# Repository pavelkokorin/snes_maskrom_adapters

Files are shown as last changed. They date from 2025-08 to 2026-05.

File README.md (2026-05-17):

# SNES/SFC Maskrom Adapters

## PSOP to DIP adapters
Adapters to replace SNES DIP32/DIP36 maskrom with PSOP44 Flash.

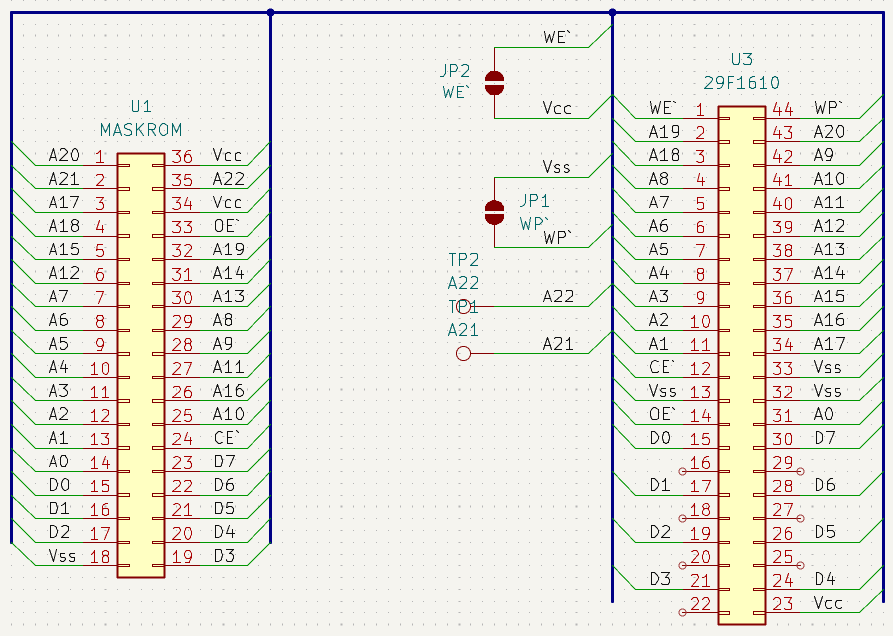
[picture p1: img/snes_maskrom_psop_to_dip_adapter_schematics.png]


### snes_maskrom_psop_to_dip_adapter
Backside PSOP44 to DIP36 adapter. Designed and tested for MX29F1610. Non destructive option, CE\`/OE\` pins of original maskrom should be cut.

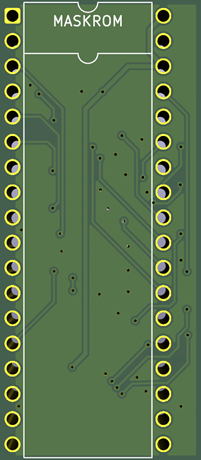
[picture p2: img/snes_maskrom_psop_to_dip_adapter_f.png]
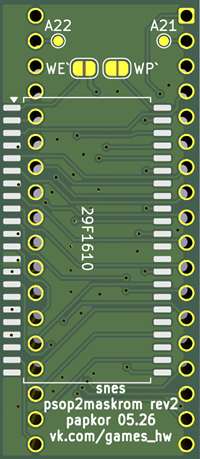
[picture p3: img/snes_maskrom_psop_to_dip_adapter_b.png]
 

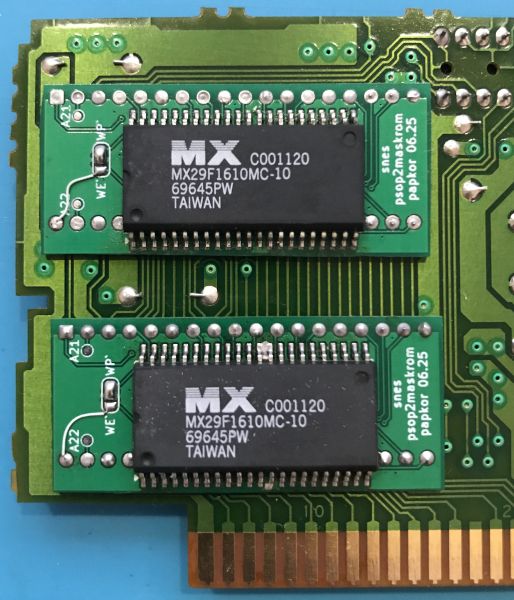
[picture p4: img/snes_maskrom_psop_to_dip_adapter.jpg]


### snes_maskrom_psop_to_dip_adapter_front
Fronside PSOP44 to DIP36 adapter. Designed and tested for MX29F1610. Replaces original maskrom.

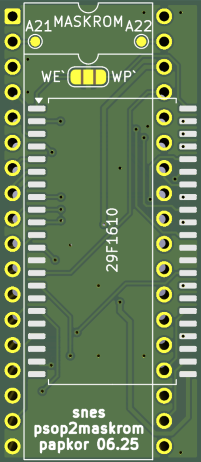
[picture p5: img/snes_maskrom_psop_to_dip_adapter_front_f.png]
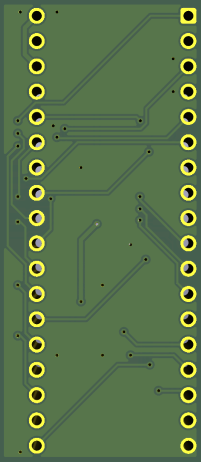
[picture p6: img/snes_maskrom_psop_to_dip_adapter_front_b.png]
 

## TSOP to DIP adapters
Adapters to replace SNES DIP32/DIP36 maskrom with TSOP40/TSOP48 Flash.

## snes_maskrom_tsop_to_dip_adapter
Backside TSOP40/TSOP48 to DIP36 adapter. Designed and tested for 29F032/29F033. Replaces original maskrom. Non destructive option, CE\`/OE\` pins of original maskrom should be cut.

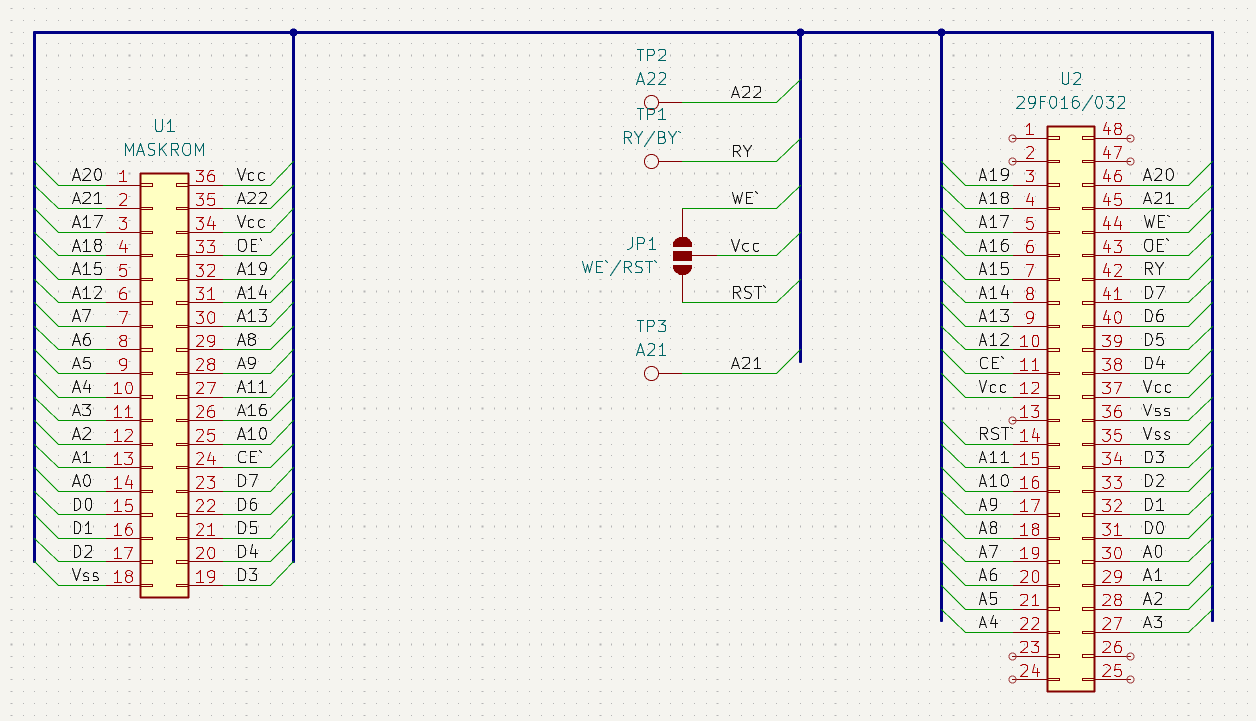
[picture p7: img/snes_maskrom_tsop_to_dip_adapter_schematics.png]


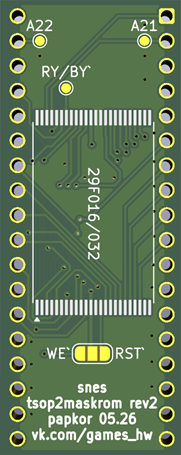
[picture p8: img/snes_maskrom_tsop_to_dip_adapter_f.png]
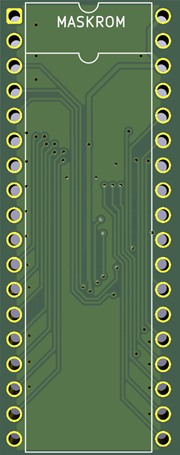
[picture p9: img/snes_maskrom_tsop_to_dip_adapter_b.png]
 

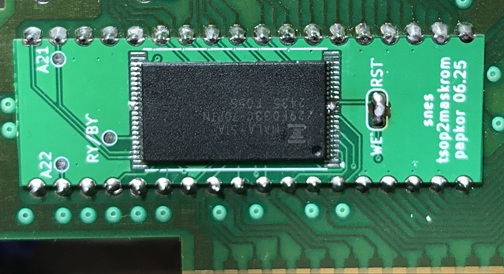
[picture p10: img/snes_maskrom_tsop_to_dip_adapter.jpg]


## snes_maskrom_tsop_to_fx_adapter
Adapters to replace SNES PSOP36/PSOP42 maskrom with TSOP40/TSOP48 Flash.

Maskroms: MX23C1601-12, M531610D-20, UPD23C4013 and other similar maskrom ICs.

Inspired by https://github.com/retrostage/SNES-SuperFX-adapter project.
Redesigned in KiCad to use less expensive production process, added some test points (WE#, RST#) for inschematic programming ability.

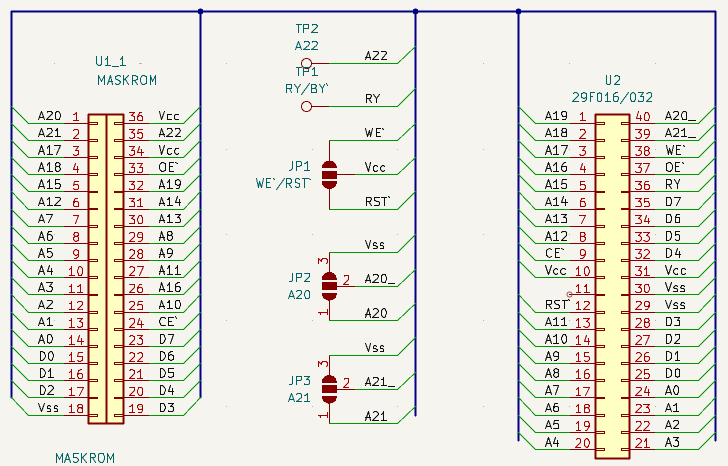
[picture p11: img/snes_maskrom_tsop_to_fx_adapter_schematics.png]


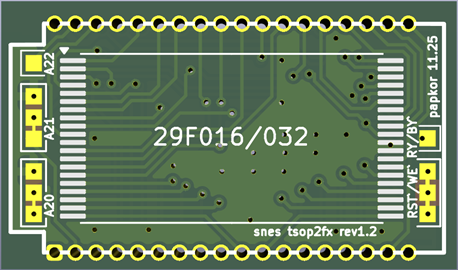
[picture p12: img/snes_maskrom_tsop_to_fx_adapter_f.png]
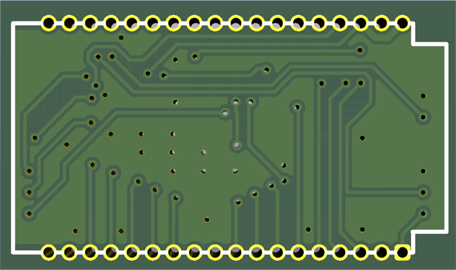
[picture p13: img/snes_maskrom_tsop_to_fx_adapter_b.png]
 

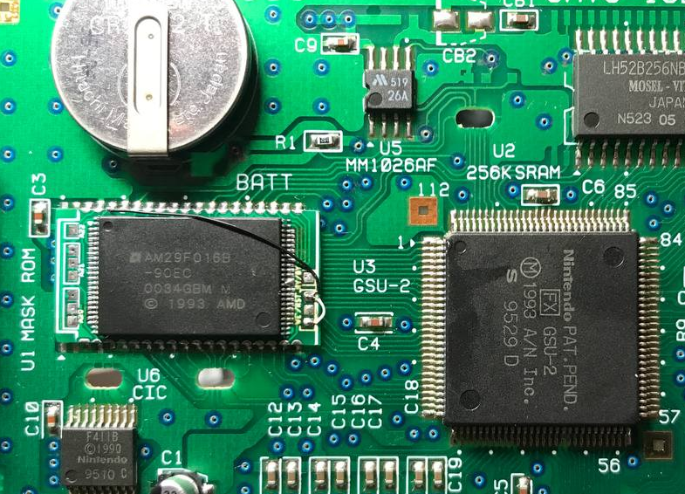
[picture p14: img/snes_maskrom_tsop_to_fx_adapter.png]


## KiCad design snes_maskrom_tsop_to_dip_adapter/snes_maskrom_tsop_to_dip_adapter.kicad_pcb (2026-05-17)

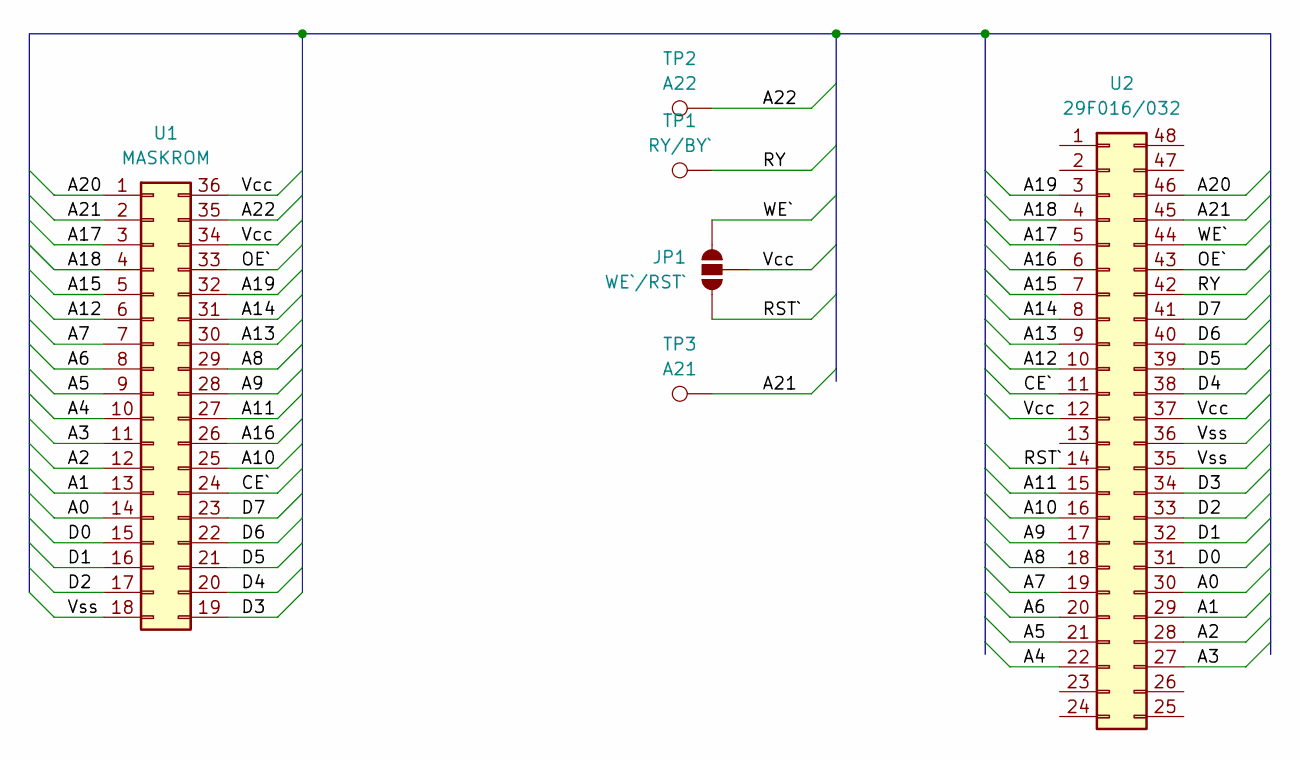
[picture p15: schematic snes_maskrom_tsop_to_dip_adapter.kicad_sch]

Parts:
JP1: WE`/RST`; SolderJumper-3_P1.3mm_Open_RoundedPad1.0x1.5mm_NumberLabels
TP1: RY/BY`; TestPoint_Pad_D1.0mm
TP2: A22; TestPoint_Pad_D1.0mm
TP3: A21; TestPoint_Pad_D1.0mm
U1: MASKROM; DIP-36_W15.24mm
U2: 29F016/032; TSOP-I-48_18.4x12mm_P0.5mm

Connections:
/A0: U1.14, U2.30
/A1: U1.13, U2.29
/A2: U1.12, U2.28
/A3: U1.11, U2.27
/A4: U1.10, U2.22
/A5: U1.9, U2.21
/A6: U1.8, U2.20
/A7: U1.7, U2.19
/A8: U1.29, U2.18
/A9: U1.28, U2.17
/A10: U1.25, U2.16
/A11: U1.27, U2.15
/A12: U1.6, U2.10
/A13: U1.30, U2.9
/A14: U1.31, U2.8
/A15: U1.5, U2.7
/A16: U1.26, U2.6
/A17: U1.3, U2.5
/A18: U1.4, U2.4
/A19: U1.32, U2.3
/A20: U1.1, U2.46
/A21: TP3.1, U1.2, U2.45
/A22: TP2.1, U1.35
/CE`: U1.24, U2.11
/D0: U1.15, U2.31
/D1: U1.16, U2.32
/D2: U1.17, U2.33
/D3: U1.19, U2.34
/D4: U1.20, U2.38
/D5: U1.21, U2.39
/D6: U1.22, U2.40
/D7: U1.23, U2.41
/OE`: U1.33, U2.43
/RST`: JP1.1 (A), U2.14
/RY: TP1.1, U2.42
/Vcc: JP1.2 (C), U1.34, U1.36, U2.12, U2.37
/Vss: U1.18, U2.35, U2.36
/WE`: JP1.3 (B), U2.44

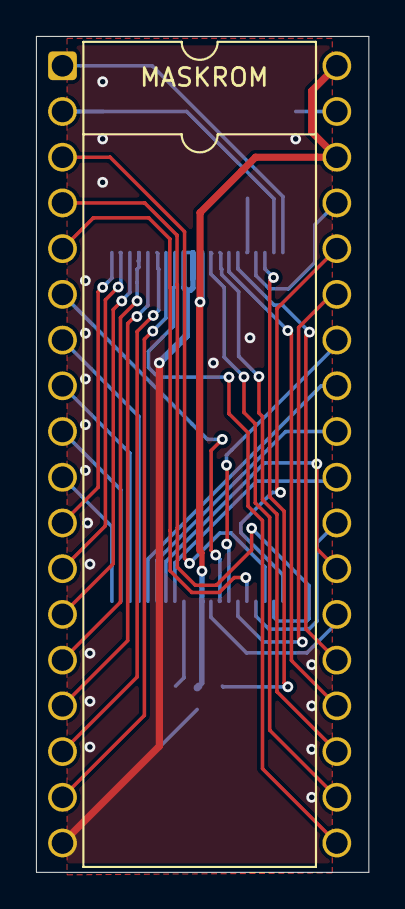
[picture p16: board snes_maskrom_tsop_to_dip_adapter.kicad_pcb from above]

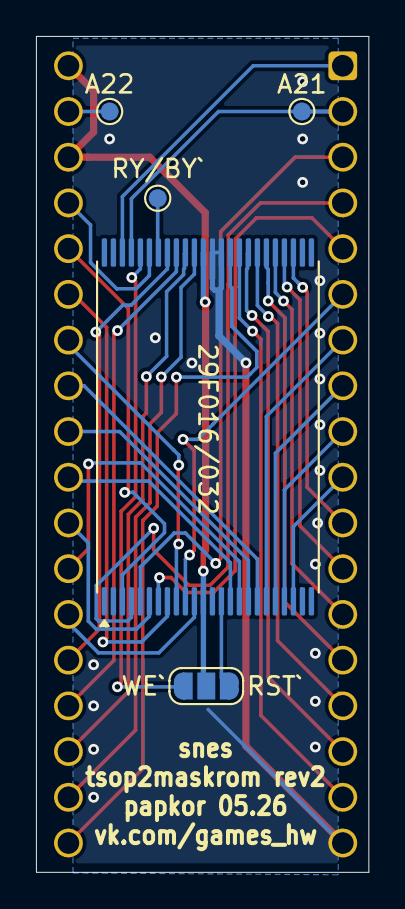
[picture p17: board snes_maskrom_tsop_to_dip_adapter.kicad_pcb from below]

Board: 2 copper layers, 18.5 x 46.4 mm, 6 parts (5 on the bottom side), 38 nets.

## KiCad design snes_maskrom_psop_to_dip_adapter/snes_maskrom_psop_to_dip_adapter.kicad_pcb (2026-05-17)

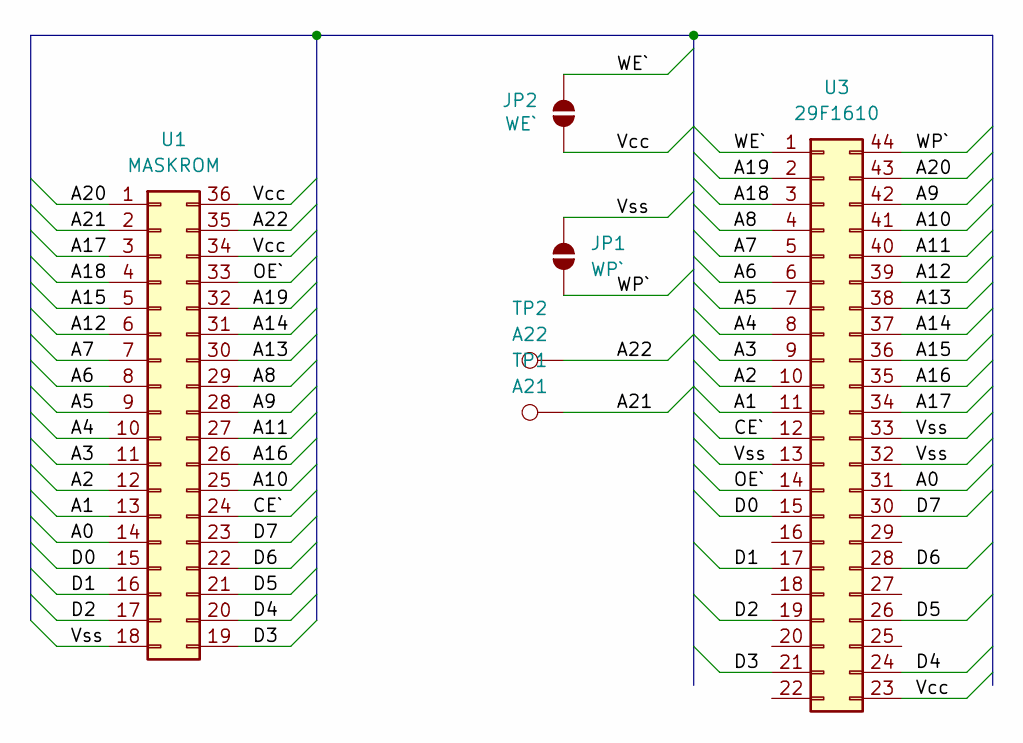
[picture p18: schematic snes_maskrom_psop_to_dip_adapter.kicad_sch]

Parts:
JP1: WP`; SolderJumper-2_P1.3mm_Open_RoundedPad1.0x1.5mm
JP2: WE`; SolderJumper-2_P1.3mm_Open_RoundedPad1.0x1.5mm
TP1: A21; TestPoint_Pad_D1.0mm
TP2: A22; TestPoint_Pad_D1.0mm
U1: MASKROM; DIP-36_W15.24mm
U3: 29F1610; SOP-44_12.6x28.5mm_P1.27mm

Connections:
/A0: U1.14, U3.31
/A1: U1.13, U3.11
/A2: U1.12, U3.10
/A3: U1.11, U3.9
/A4: U1.10, U3.8
/A5: U1.9, U3.7
/A6: U1.8, U3.6
/A7: U1.7, U3.5
/A8: U1.29, U3.4
/A9: U1.28, U3.42
/A10: U1.25, U3.41
/A11: U1.27, U3.40
/A12: U1.6, U3.39
/A13: U1.30, U3.38
/A14: U1.31, U3.37
/A15: U1.5, U3.36
/A16: U1.26, U3.35
/A17: U1.3, U3.34
/A18: U1.4, U3.3
/A19: U1.32, U3.2
/A20: U1.1, U3.43
/A21: TP1.1, U1.2
/A22: TP2.1, U1.35
/CE`: U1.24, U3.12
/D0: U1.15, U3.15
/D1: U1.16, U3.17
/D2: U1.17, U3.19
/D3: U1.19, U3.21
/D4: U1.20, U3.24
/D5: U1.21, U3.26
/D6: U1.22, U3.28
/D7: U1.23, U3.30
/OE`: U1.33, U3.14
/Vcc: JP2.1 (A), U1.34, U1.36, U3.23
/Vss: JP1.2 (B), U1.18, U3.13, U3.32, U3.33
/WE`: JP2.2 (B), U3.1
/WP`: JP1.1 (A), U3.44

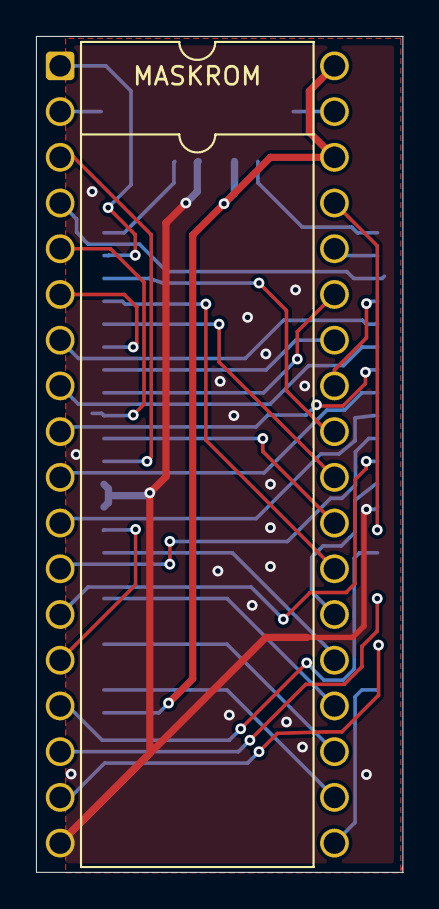
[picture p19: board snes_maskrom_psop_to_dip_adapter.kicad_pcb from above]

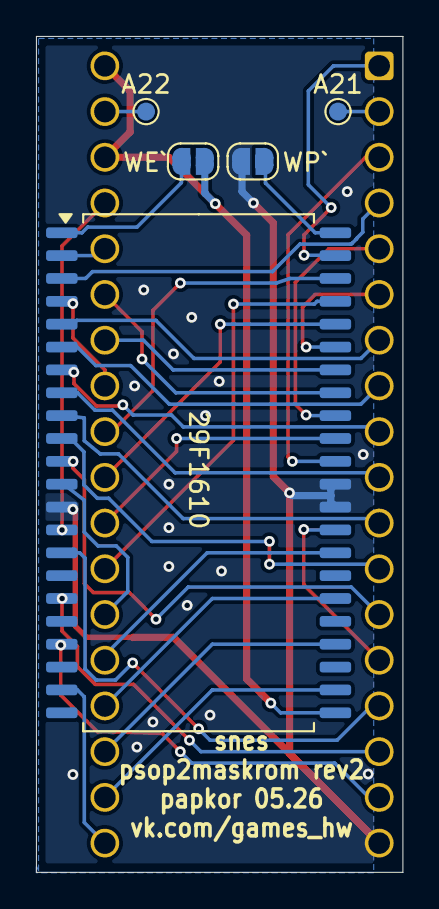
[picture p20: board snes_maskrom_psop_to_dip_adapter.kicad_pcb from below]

Board: 2 copper layers, 20.4 x 46.4 mm, 6 parts (5 on the bottom side), 37 nets.

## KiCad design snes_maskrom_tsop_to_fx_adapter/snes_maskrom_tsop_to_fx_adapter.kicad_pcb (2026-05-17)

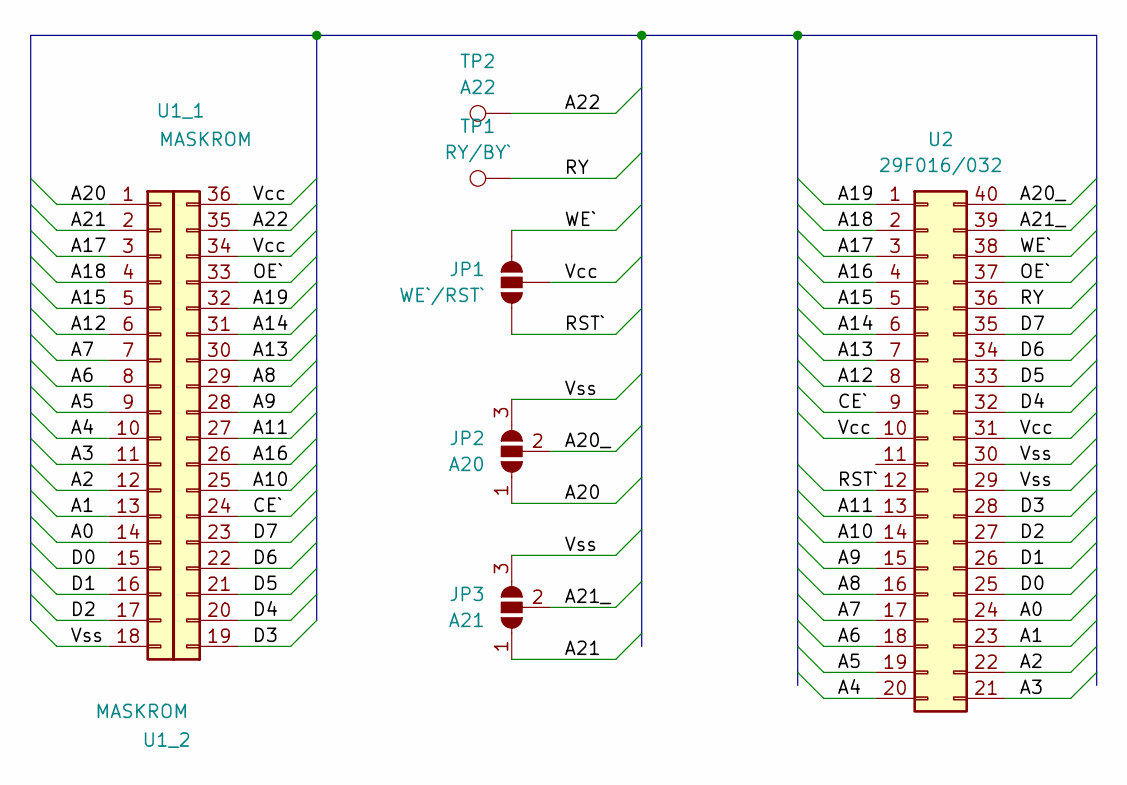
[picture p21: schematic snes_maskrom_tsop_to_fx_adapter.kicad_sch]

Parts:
JP1: WE`/RST`; SolderJumper-3_P1.3mm_Bridged123_Pad1.0x1.5mm_NumberLabels
JP2: A20; SolderJumper-3_P1.3mm_Bridged12_Pad1.0x1.5mm_NumberLabels
JP3: A21; SolderJumper-3_P1.3mm_Bridged12_Pad1.0x1.5mm_NumberLabels
TP1: RY/BY`; TestPoint_Pad_D1.0mm
TP2: A22; TestPoint_Pad_D1.0mm
U1_1, U1_2: MASKROM; PinHeader_1x18_P1.27mm_Vertical
U2: 29F016/032; TSOP-I-40_18.4x10mm_P0.5mm

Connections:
/A0: U1_1.14, U2.24
/A1: U1_1.13, U2.23
/A2: U1_1.12, U2.22
/A3: U1_1.11, U2.21
/A4: U1_1.10, U2.20
/A5: U1_1.9, U2.19
/A6: U1_1.8, U2.18
/A7: U1_1.7, U2.17
/A8: U1_2.29, U2.16
/A9: U1_2.28, U2.15
/A10: U1_2.25, U2.14
/A11: U1_2.27, U2.13
/A12: U1_1.6, U2.8
/A13: U1_2.30, U2.7
/A14: U1_2.31, U2.6
/A15: U1_1.5, U2.5
/A16: U1_2.26, U2.4
/A17: U1_1.3, U2.3
/A18: U1_1.4, U2.2
/A19: U1_2.32, U2.1
/A20: JP2.1 (A), U1_1.1
/A20_: JP2.2 (C), U2.40
/A21: JP3.1 (A), U1_1.2
/A21_: JP3.2 (C), U2.39
/A22: TP2.1, U1_2.35
/CE`: U1_2.24, U2.9
/D0: U1_1.15, U2.25
/D1: U1_1.16, U2.26
/D2: U1_1.17, U2.27
/D3: U1_2.19, U2.28
/D4: U1_2.20, U2.32
/D5: U1_2.21, U2.33
/D6: U1_2.22, U2.34
/D7: U1_2.23, U2.35
/OE`: U1_2.33, U2.37
/RST`: JP1.1 (A), U2.12
/RY: TP1.1, U2.36
/Vcc: JP1.2 (C), U1_2.34, U1_2.36, U2.10, U2.31
/Vss: JP2.3 (B), JP3.3 (B), U1_1.18, U2.29, U2.30
/WE`: JP1.3 (B), U2.38

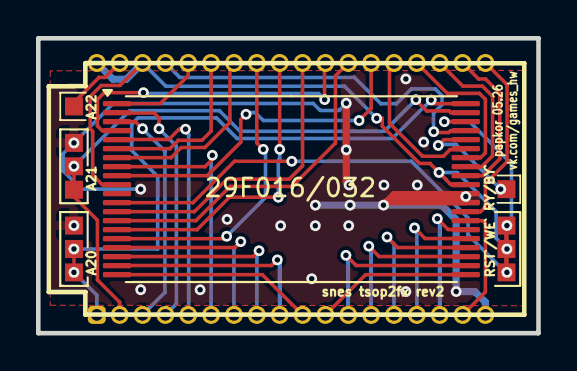
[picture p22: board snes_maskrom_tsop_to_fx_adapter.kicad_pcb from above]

Board: 2 copper layers, 27.8 x 16.4 mm, 8 parts (0 on the bottom side), 40 nets.

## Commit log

2025-08-26 Added snes psop to dip adapters
    [snes_maskrom_psop_to_dip_adapter.kicad_pcb, snes_maskrom_psop_to_dip_adapter.kicad_sch, snes_maskrom_psop_to_dip_adapter_front.kicad_pcb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]
2025-11-27 added snes_maskrom_tsop_to_fx_adapter
    [snes_maskrom_tsop_to_fx_adapter.kicad_pcb, snes_maskrom_tsop_to_fx_adapter.kicad_sch]
2026-05-04 added snes_maskrom_tsop_to_dip_adapter
    [snes_maskrom_tsop_to_dip_adapter.kicad_pcb, snes_maskrom_tsop_to_dip_adapter.kicad_sch]
2026-05-17 update img and gerbers
    [snes_maskrom_psop_to_dip_adapter.kicad_pcb, snes_maskrom_psop_to_dip_adapter.kicad_sch, snes_maskrom_tsop_to_dip_adapter.kicad_pcb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]
